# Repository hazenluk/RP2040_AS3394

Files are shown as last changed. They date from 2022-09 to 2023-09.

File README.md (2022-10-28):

# RP2040_AS3394
An AS3394 Voice Card controlled by RP2040.

Schematics and Routing in KiCad. Uses 30Khz PWM with 12-bit duty cycle and 1KHz Low Pass filtering to produce control voltages.

Mainly a way for me to learn and experiment with discrete Sallen-Key and MFB filters. Also a way to avoid out-of-stock DACs during the chip shortage.

Work-In-Progress photo of board:
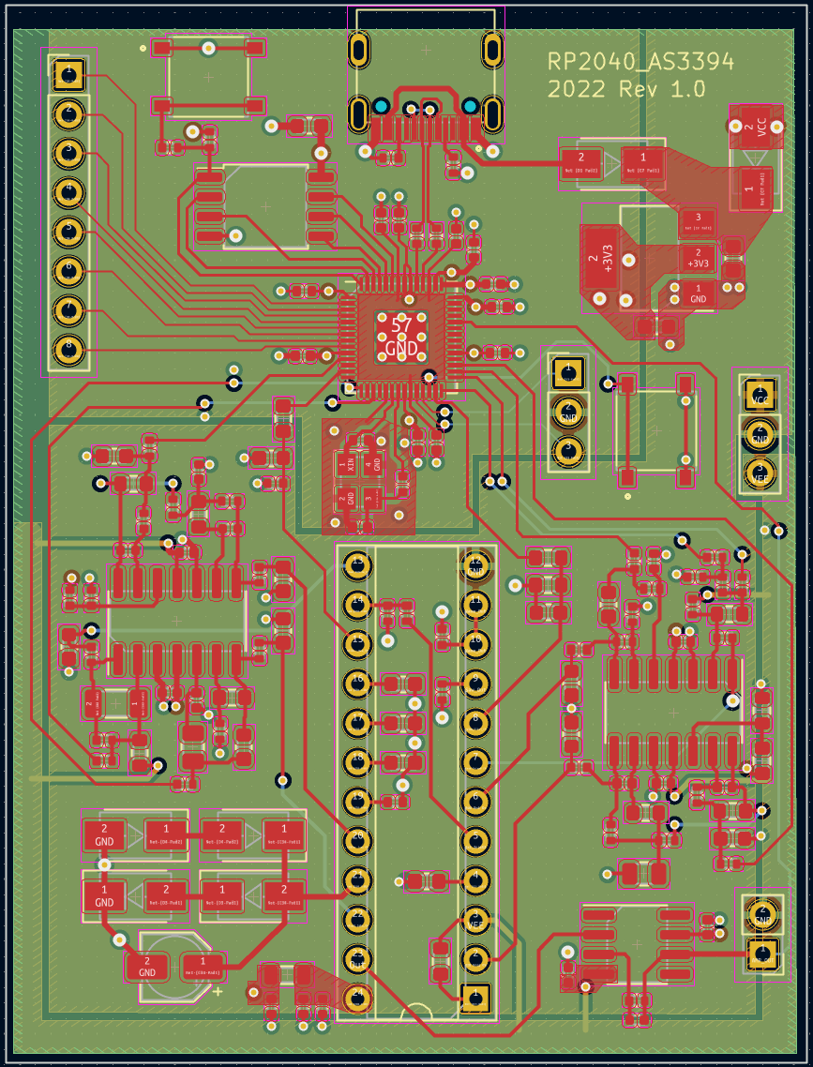
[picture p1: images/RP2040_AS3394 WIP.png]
WIP image of board


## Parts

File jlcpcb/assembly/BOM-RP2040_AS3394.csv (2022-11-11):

Comment | Designator | Footprint | LCSC
120R | FB1 | L_0805_2012Metric | C1015
TL071 | U7 | SOIC-8_3.9x4.9mm_P1.27mm | C107648
1k | R11,R35,R40,R49,R5,R7 | R_0402_1005Metric | C11702
22u | C42 | C_1206_3216Metric | C12891
2k7 | R28,R52 | R_0603_1608Metric | C13167
100n | C16 | C_0603_1608Metric | C14663
NCP1117-3.3_SOT223 | U2 | SOT-223-3_TabPin2 | C146799
10n | C19,C20,C23,C27,C28,C38,C40 | C_0402_1005Metric | C15195
0.1u | C43,C44,C47,C48,C50,C51 | C_0402_1005Metric | C1525
47p | C52 | C_0402_1005Metric | C1567
30p | C14,C15 | C_0402_1005Metric | C1570
1n5 | C17 | C_0603_1608Metric | C1595
15n | C21,C22 | C_0603_1608Metric | C1596
47n | C45,C46 | C_0603_1608Metric | C1622
.047u | C24,C25,C30,C41,C49 | C_0603_1608Metric | C1623
TYPE-C-31-M-12 | J2 | HRO_TYPE-C-31-M-12 | C165948
220n | C39 | C_0402_1005Metric | C16772
16k | R13 | R_0805_2012Metric | C17490
RP2040 | U1 | QFN-56-1EP_7x7mm_P0.4mm_EP3.2x3.2mm | C2040
33n | C18,C32,C33,C35,C37 | C_0603_1608Metric | C21117
D_Schottky | D1,D2 | D_SMA | C22452
3k6 | R45 | R_0603_1608Metric | C22980
4k3 | R50 | R_0603_1608Metric | C23159
560 | R24 | R_0603_1608Metric | C23204
750 | R23 | R_0603_1608Metric | C23241
9k1 | R43 | R_0603_1608Metric | C23260
100 | R30,R48,R57 | R_0402_1005Metric | C25076
120 | R25,R26 | R_0402_1005Metric | C25079
4u7 | C34 | CP_Elec_4x5.4 | C250890
300 | R36 | R_0402_1005Metric | C25102
510 | R14,R22 | R_0402_1005Metric | C25123
10k | R10,R55 | R_0402_1005Metric | C25744
12k | R9 | R_0402_1005Metric | C25752
15k | R12 | R_0402_1005Metric | C25756
18k | R47 | R_0402_1005Metric | C25762
33k | R44 | R_0402_1005Metric | C25779
1k5 | R56 | R_0402_1005Metric | C25867
2k2 | R41 | R_0402_1005Metric | C25879
2k4 | R17,R18 | R_0402_1005Metric | C25882
3k3 | R27,R46 | R_0402_1005Metric | C25890
5.1k | R1,R2,R29 | R_0402_1005Metric | C25905
6k8 | R19,R31,R32,R8 | R_0402_1005Metric | C25917
7.5k | R16 | R_0402_1005Metric | C25918
1k6 | R33 | R_0402_1005Metric | C25931
11k | R21,R34 | R_0603_1608Metric | C25950
100n | C1,C10,C11,C13,C3,C4,C6,C8,C9 | C_0402_1005Metric | C307331
27r4 | R3,R4 | R_0402_1005Metric | C31439
560p | C31 | C_0402_1005Metric | C318606
TS-1187A-B-A-B | S1,S2 | SW_TS-1187A-B-A-B | C318884
68k | R37 | R_0402_1005Metric | C36871
2k | R38,R39,R42 | R_0402_1005Metric | C4109
240k | R15 | R_0603_1608Metric | C4197
3k | R20,R54 | R_0603_1608Metric | C4211
6k2 | R53 | R_0603_1608Metric | C4260
1u | C2,C29,C36,C5 | C_0402_1005Metric | C52923
180n | C26 | C_0805_2012Metric | C67952
LM324 | U4,U6 | SOIC-14_3.9x8.7mm_P1.27mm | C71035
X322512MSB4SI | Y1 | Crystal_SMD_3225-4Pin_3.2x2.5mm | C9002
D_Small | D3,D4,D5,D6 | D_SMA | C95872
10u | C12,C7 | C_0603_1608Metric | C96446
W25Q128JVS | U3 | SOIC-8_5.23x5.23mm_P1.27mm | C97521
DNF | R6 | R_0402_1005Metric
Conn_01x08 | J4 | PinHeader_1x08_P2.54mm_Vertical
AS3394 | U5 | DIP-24_W7.62mm_Socket
Conn_01x03 | J1 | PinHeader_1x03_P2.54mm_Vertical
Conn_01x02 | J3 | PinHeader_1x02_P2.54mm_Vertical
Conn_01x03 | J5 | PinHeader_1x03_P2.54mm_Vertical

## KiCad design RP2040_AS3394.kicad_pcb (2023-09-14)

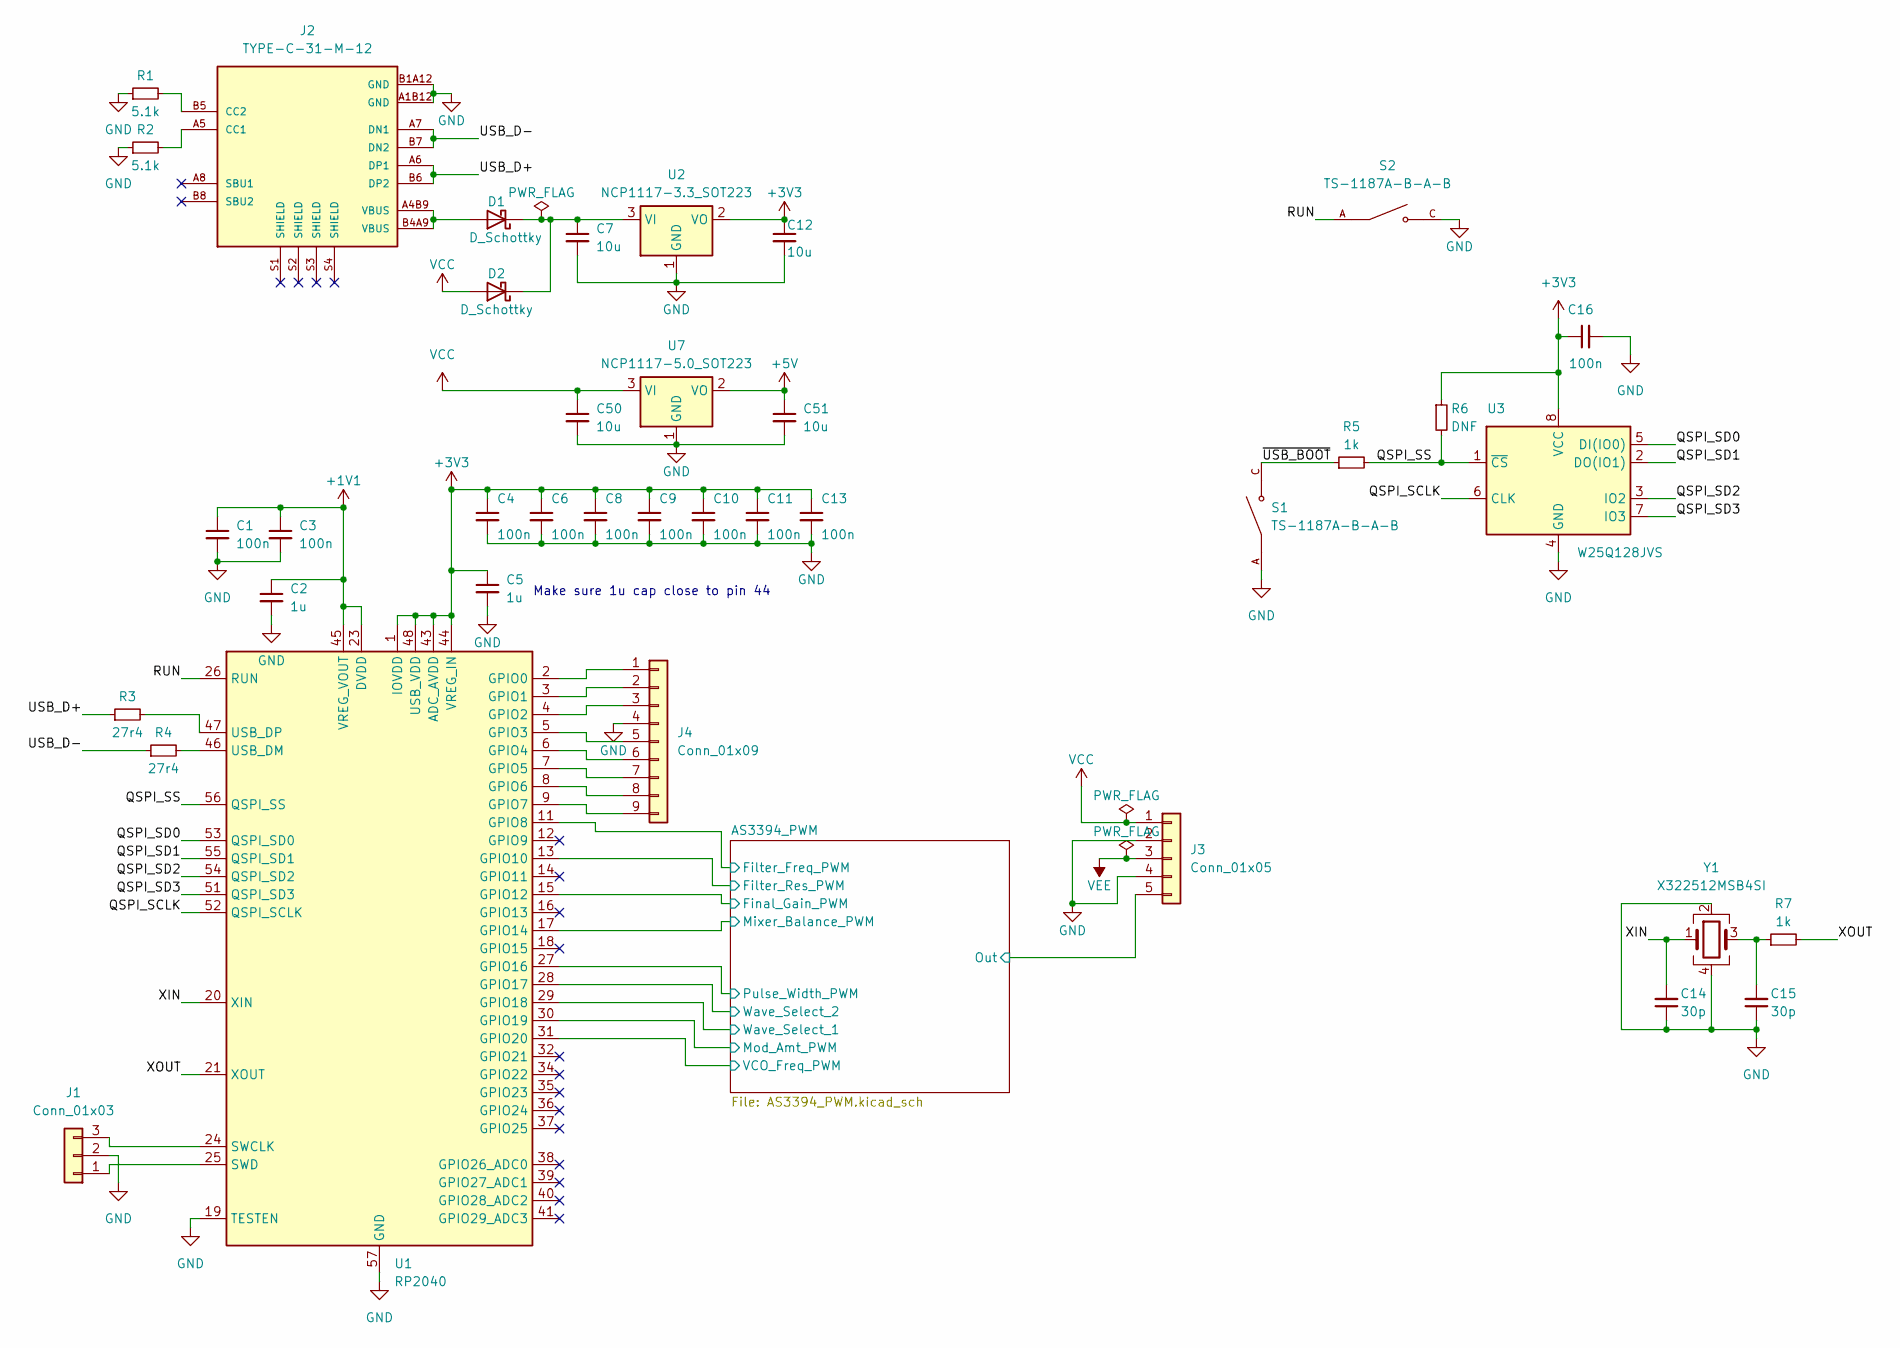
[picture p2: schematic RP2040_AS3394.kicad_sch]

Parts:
C1, C3, C4, C6, C8, C9, C10, C11, C13: 100n; C_0402_1005Metric
C2, C5: 1u; C_0402_1005Metric
C7, C12, C50, C51: 10u; C_0603_1608Metric
C14, C15: 30p; C_0402_1005Metric
C16: 100n; C_0603_1608Metric
D1, D2: D_Schottky; D_SMA
J1: Conn_01x03; PinHeader_1x03_P2.54mm_Vertical
J2: TYPE-C-31-M-12; HRO_TYPE-C-31-M-12; PARTREV A
J3: Conn_01x05; PinHeader_1x05_P2.54mm_Vertical
J4: Conn_01x09; PinHeader_1x09_P2.54mm_Vertical
R1, R2: 5.1k; R_0402_1005Metric
R3, R4: 27r4; R_0402_1005Metric
R5, R7: 1k; R_0402_1005Metric
R6: DNF; R_0402_1005Metric
S1, S2: TS-1187A-B-A-B; SW_TS-1187A-B-A-B; PARTREV A0
U1: RP2040; QFN-56-1EP_7x7mm_P0.4mm_EP3.2x3.2mm
U2: NCP1117-3.3_SOT223; SOT-223-3_TabPin2
U3: W25Q128JVS; SOIC-8_5.23x5.23mm_P1.27mm
U7: NCP1117-5.0_SOT223; SOT-223-3_TabPin2
Y1: X322512MSB4SI; Crystal_SMD_3225-4Pin_3.2x2.5mm

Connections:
+1V1: C1.1, C2.1, C3.1, U1.23 (DVDD), U1.45 (VREG_VOUT), U1.50 (DVDD)
+3V3: C4.1, C5.1, C6.1, C8.1, C9.1, C10.1, C11.1, C12.1, C13.1, C16.1, R6.1, U1.1 (IOVDD), U1.10 (IOVDD), U1.22 (IOVDD), U1.33 (IOVDD), U1.42 (IOVDD), U1.43 (ADC_AVDD), U1.44 (VREG_IN), U1.48 (USB_VDD), U1.49 (IOVDD), U2.2 (VO), U3.8 (VCC)
+5V: C51.1, U7.2 (VO); also elsewhere on the board
/AS3394_PWM/Filter_Freq_PWM: U1.11 (GPIO8); also elsewhere on the board
/AS3394_PWM/Filter_Res_PWM: U1.13 (GPIO10); also elsewhere on the board
/AS3394_PWM/Final_Gain_PWM: U1.15 (GPIO12); also elsewhere on the board
/AS3394_PWM/Mixer_Balance_PWM: U1.17 (GPIO14); also elsewhere on the board
/AS3394_PWM/Mod_Amt_PWM: U1.30 (GPIO19); also elsewhere on the board
/AS3394_PWM/Out: J3.5; also elsewhere on the board
/AS3394_PWM/Pulse_Width_PWM: U1.27 (GPIO16); also elsewhere on the board
/AS3394_PWM/VCO_Freq_PWM: U1.31 (GPIO20); also elsewhere on the board
/AS3394_PWM/Wave_Select_1: U1.29 (GPIO18); also elsewhere on the board
/AS3394_PWM/Wave_Select_2: U1.28 (GPIO17); also elsewhere on the board
/QSPI_SCLK: U1.52 (QSPI_SCLK), U3.6 (CLK)
/QSPI_SD0: U1.53 (QSPI_SD0), U3.5 (DI(IO0))
/QSPI_SD1: U1.55 (QSPI_SD1), U3.2 (DO(IO1))
/QSPI_SD2: U1.54 (QSPI_SD2), U3.3 (IO2)
/QSPI_SD3: U1.51 (QSPI_SD3), U3.7 (IO3)
/QSPI_SS: R5.2, R6.2, U1.56 (QSPI_SS), U3.1 (~CS)
/RUN: S2.A, S2.B, U1.26 (RUN)
/USB_D+: J2.A6 (DP1), J2.B6 (DP2), R3.1
/USB_D-: J2.A7 (DN1), J2.B7 (DN2), R4.1
/XIN: C14.2, U1.20 (XIN), Y1.1
/XOUT: R7.2, U1.21 (XOUT)
/~USB_BOOT: R5.1, S1.C, S1.D
GND: C1.2, C2.2, C3.2, C4.2, C5.2, C6.2, C7.2, C8.2, C9.2, C10.2, C11.2, C12.2, C13.2, C14.1, C15.1, C16.2, C50.2, C51.2, J1.2, J2.A1B12 (GND), J2.B1A12 (GND), J3.2, J3.4, J4.4, R1.1, R2.1, S1.A, S1.B, S2.C, S2.D, U1.19 (TESTEN), U1.57 (GND), U2.1 (GND), U3.4 (GND), U7.1 (GND), Y1.2, Y1.4; also elsewhere on the board
unnamed: C15.2, R7.1, Y1.3
unnamed: D1.2 (A), J2.A4B9 (VBUS), J2.B4A9 (VBUS)
unnamed: C7.1, D1.1 (K), D2.1 (K), U2.3 (VI)
unnamed: J1.1, U1.25 (SWD)
unnamed: J1.3, U1.24 (SWCLK)
unnamed: J2.A5 (CC1), R2.2
unnamed: J2.B5 (CC2), R1.2
unnamed: J4.1, U1.2 (GPIO0)
unnamed: J4.2, U1.3 (GPIO1)
unnamed: J4.3, U1.4 (GPIO2)
unnamed: J4.5, U1.5 (GPIO3)
unnamed: J4.6, U1.6 (GPIO4)
unnamed: J4.7, U1.7 (GPIO5)
unnamed: J4.8, U1.8 (GPIO6)
unnamed: J4.9, U1.9 (GPIO7)
unnamed: R4.2, U1.46 (USB_DM)
unnamed: R3.2, U1.47 (USB_DP)
VCC: C50.1, D2.2 (A), J3.1, U7.3 (VI); also elsewhere on the board
VEE: J3.3; also elsewhere on the board

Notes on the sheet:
Make sure 1u cap close to pin 44

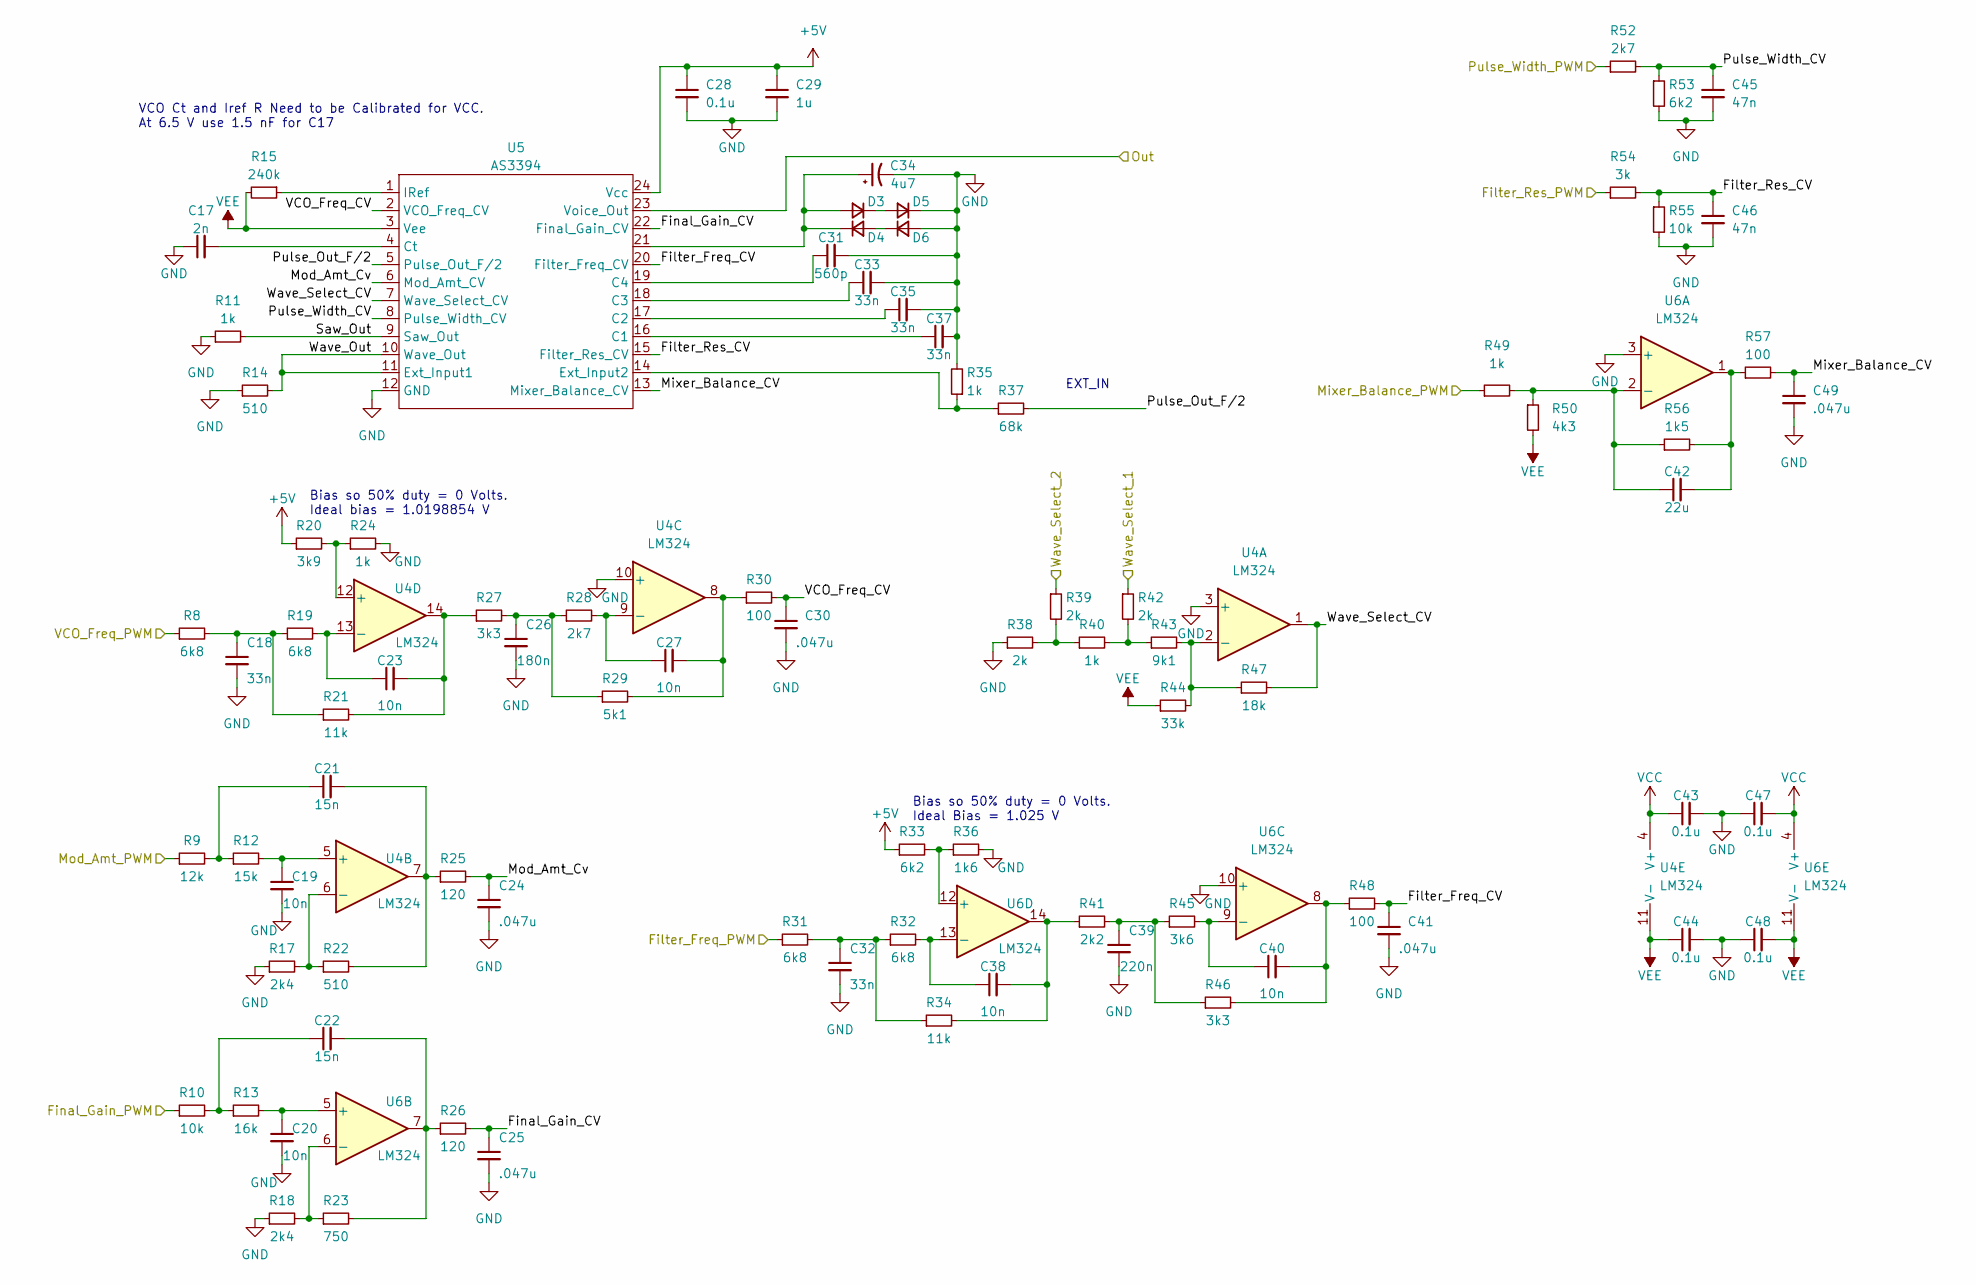
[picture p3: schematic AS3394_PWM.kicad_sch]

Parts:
C17: 2n; C_0603_1608Metric
C18, C32, C33, C35, C37: 33n; C_0603_1608Metric
C19, C20, C23, C27, C38, C40: 10n; C_0402_1005Metric
C21, C22: 15n; C_0603_1608Metric
C24, C25, C30, C41, C49: .047u; C_0603_1608Metric
C26: 180n; C_0805_2012Metric
C28, C43, C44, C47, C48: 0.1u; C_0402_1005Metric
C29: 1u; C_0402_1005Metric
C31: 560p; C_0402_1005Metric
C34: 4u7; CP_Elec_4x5.4
C39: 220n; C_0402_1005Metric
C42: 22u; C_1206_3216Metric
C45, C46: 47n; C_0603_1608Metric
D3, D4, D5, D6: D_Small; D_SOD-123
R8, R19, R31, R32: 6k8; R_0402_1005Metric
R9: 12k; R_0402_1005Metric
R10, R55: 10k; R_0402_1005Metric
R11, R24, R35, R40, R49: 1k; R_0402_1005Metric
R12: 15k; R_0402_1005Metric
R13: 16k; R_0805_2012Metric
R14, R22: 510; R_0402_1005Metric
R15: 240k; R_0603_1608Metric
R17, R18: 2k4; R_0402_1005Metric
R20: 3k9; R_0402_1005Metric
R21, R34: 11k; R_0603_1608Metric
R23: 750; R_0603_1608Metric
R25, R26: 120; R_0402_1005Metric
R27, R46: 3k3; R_0402_1005Metric
R28, R52: 2k7; R_0603_1608Metric
R29: 5k1; R_0402_1005Metric
R30, R48, R57: 100; R_0402_1005Metric
R33, R53: 6k2; R_0603_1608Metric
R36: 1k6; R_0402_1005Metric
R37: 68k; R_0402_1005Metric
R38, R39, R42: 2k; R_0402_1005Metric
R41: 2k2; R_0402_1005Metric
R43: 9k1; R_0603_1608Metric
R44: 33k; R_0402_1005Metric
R45: 3k6; R_0603_1608Metric
R47: 18k; R_0402_1005Metric
R50: 4k3; R_0603_1608Metric
R54: 3k; R_0603_1608Metric
R56: 1k5; R_0402_1005Metric
U4, U6: LM324; SOIC-14_3.9x8.7mm_P1.27mm
U5: AS3394; DIP-24_W7.62mm_Socket

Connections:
+5V: C28.1, C29.1, R20.1, R33.1, U5.24 (Vcc); also elsewhere on the board
/AS3394_PWM/Filter_Freq_CV: C41.1, R48.2, U5.20 (Filter_Freq_CV)
/AS3394_PWM/Filter_Freq_PWM: R31.1; also elsewhere on the board
/AS3394_PWM/Filter_Res_CV: C46.1, R54.2, R55.1, U5.15 (Filter_Res_CV)
/AS3394_PWM/Filter_Res_PWM: R54.1; also elsewhere on the board
/AS3394_PWM/Final_Gain_CV: C25.1, R26.2, U5.22 (Final_Gain_CV)
/AS3394_PWM/Final_Gain_PWM: R10.1; also elsewhere on the board
/AS3394_PWM/Mixer_Balance_CV: C49.1, R57.2, U5.13 (Mixer_Balance_CV)
/AS3394_PWM/Mixer_Balance_PWM: R49.1; also elsewhere on the board
/AS3394_PWM/Mod_Amt_Cv: C24.1, R25.2, U5.6 (Mod_Amt_CV)
/AS3394_PWM/Mod_Amt_PWM: R9.1; also elsewhere on the board
/AS3394_PWM/Out: U5.23 (Voice_Out); also elsewhere on the board
/AS3394_PWM/Pulse_Out_F/2: R37.2, U5.5 (Pulse_Out_F/2)
/AS3394_PWM/Pulse_Width_CV: C45.1, R52.2, R53.1, U5.8 (Pulse_Width_CV)
/AS3394_PWM/Pulse_Width_PWM: R52.1; also elsewhere on the board
/AS3394_PWM/Saw_Out: R11.2, U5.9 (Saw_Out)
/AS3394_PWM/VCO_Freq_CV: C30.1, R30.2, U5.2 (VCO_Freq_CV)
/AS3394_PWM/VCO_Freq_PWM: R8.1; also elsewhere on the board
/AS3394_PWM/Wave_Out: R14.2, U5.10 (Wave_Out), U5.11 (Ext_Input1)
/AS3394_PWM/Wave_Select_1: R42.1; also elsewhere on the board
/AS3394_PWM/Wave_Select_2: R39.1; also elsewhere on the board
/AS3394_PWM/Wave_Select_CV: R47.2, U4.1, U5.7 (Wave_Select_CV)
GND: C17.1, C18.2, C19.2, C20.2, C24.2, C25.2, C26.2, C28.2, C29.2, C30.2, C31.2, C32.2, C33.2, C34.2, C35.2, C37.2, C39.2, C41.2, C43.2, C44.2, C45.2, C46.2, C47.1, C48.1, C49.2, D5.1 (K), D6.2 (A), R11.1, R14.1, R17.1, R18.1, R24.2, R35.2, R36.2, R38.1, R53.2, R55.2, U4.3 (+), U4.10 (+), U5.12 (GND), U6.3 (+), U6.10 (+); also elsewhere on the board
unnamed: C18.1, R8.2, R19.1, R21.1
unnamed: C21.1, R9.2, R12.1
unnamed: C21.2, R22.2, R25.1, U4.7
unnamed: C22.1, R10.2, R13.1
unnamed: C22.2, R23.2, R26.1, U6.7
unnamed: C23.2, R21.2, R27.1, U4.14
unnamed: C26.1, R27.2, R28.1, R29.1
unnamed: C27.2, R29.2, R30.1, U4.8
unnamed: C32.1, R31.2, R32.1, R34.1
unnamed: C38.2, R34.2, R41.1, U6.14
unnamed: C39.1, R41.2, R45.1, R46.1
unnamed: C40.2, R46.2, R48.1, U6.8
unnamed: C42.2, R56.2, R57.1, U6.1
unnamed: C34.1, D3.2 (A), D4.1 (K), U5.21
unnamed: D3.1 (K), D5.2 (A)
unnamed: D4.2 (A), D6.1 (K)
unnamed: R38.2, R39.2, R40.1
unnamed: R40.2, R42.2, R43.1
unnamed: R43.2, R44.2, R47.1, U4.2 (-)
unnamed: C19.1, R12.2, U4.5 (+)
unnamed: R17.2, R22.1, U4.6 (-)
unnamed: C27.1, R28.2, U4.9 (-)
unnamed: R20.2, R24.1, U4.12 (+)
unnamed: C23.1, R19.2, U4.13 (-)
unnamed: C37.1, U5.16 (C1)
unnamed: C35.1, U5.17 (C2)
unnamed: C33.1, U5.18 (C3)
unnamed: C31.1, U5.19 (C4)
unnamed: C17.2, U5.4 (Ct)
unnamed: R35.1, R37.1, U5.14 (Ext_Input2)
unnamed: R15.1, U5.1 (IRef)
unnamed: C42.1, R49.2, R50.1, R56.1, U6.2 (-)
unnamed: C20.1, R13.2, U6.5 (+)
unnamed: R18.2, R23.1, U6.6 (-)
unnamed: C40.1, R45.2, U6.9 (-)
unnamed: R33.2, R36.1, U6.12 (+)
unnamed: C38.1, R32.2, U6.13 (-)
VCC: C43.1, C47.2, U4.4 (V+), U6.4 (V+); also elsewhere on the board
VEE: C44.1, C48.2, R15.2, R44.1, R50.2, U4.11 (V-), U5.3 (Vee), U6.11 (V-); also elsewhere on the board

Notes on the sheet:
Bias so 50% duty = 0 Volts. Ideal Bias = 1.025 V
EXT_IN
Bias so 50% duty = 0 Volts. Ideal bias = 1.0198854 V
VCO Ct and Iref R Need to be Calibrated for VCC. At 6.5 V use 1.5 nF for C17

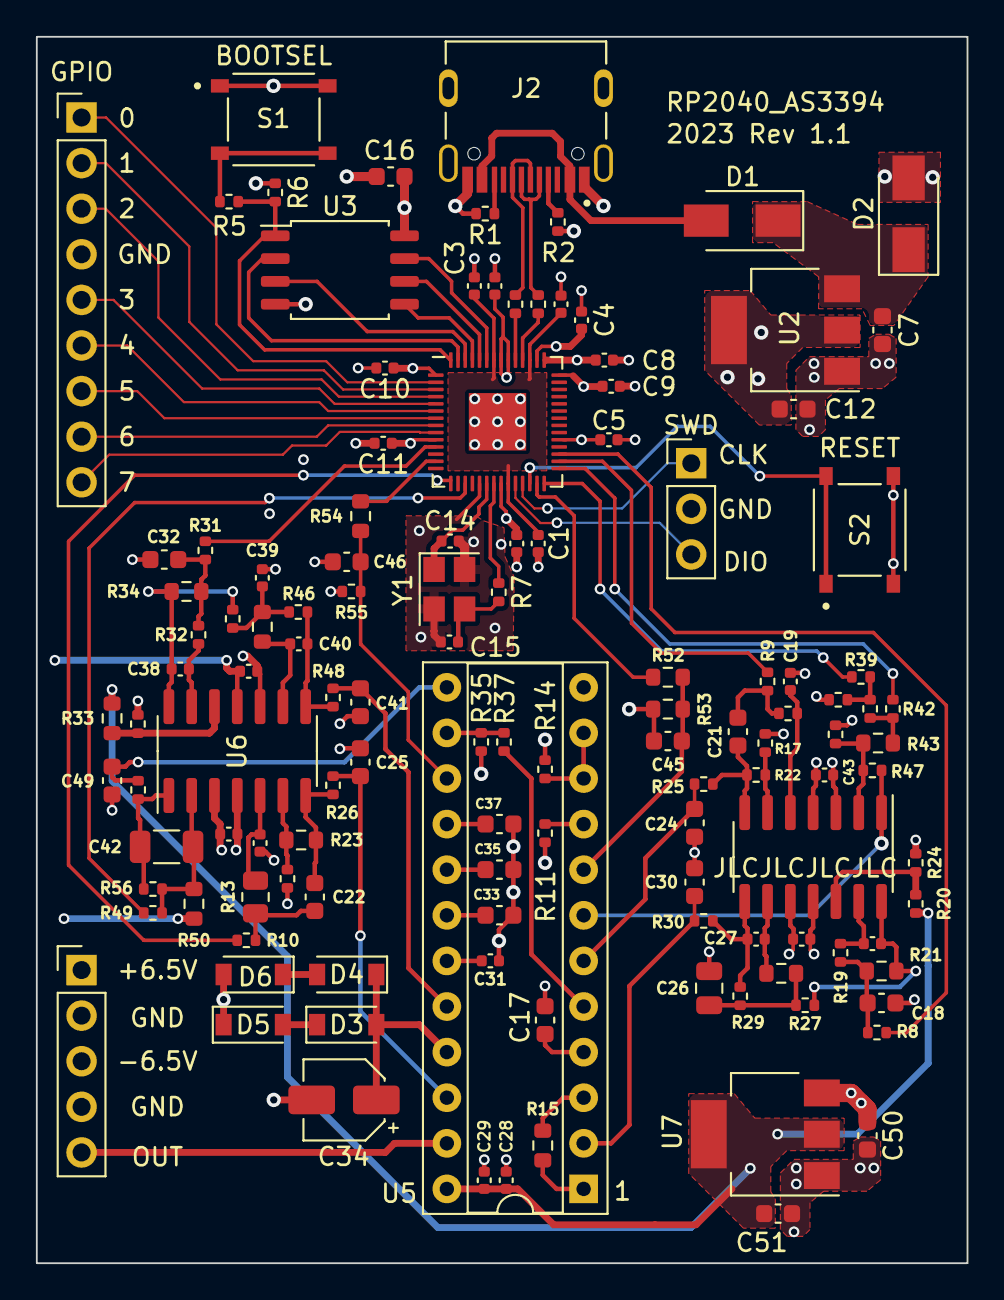
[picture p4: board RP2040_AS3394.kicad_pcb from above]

Board: 4 copper layers, 51.8 x 68.3 mm, 125 parts (0 on the bottom side), 93 nets.

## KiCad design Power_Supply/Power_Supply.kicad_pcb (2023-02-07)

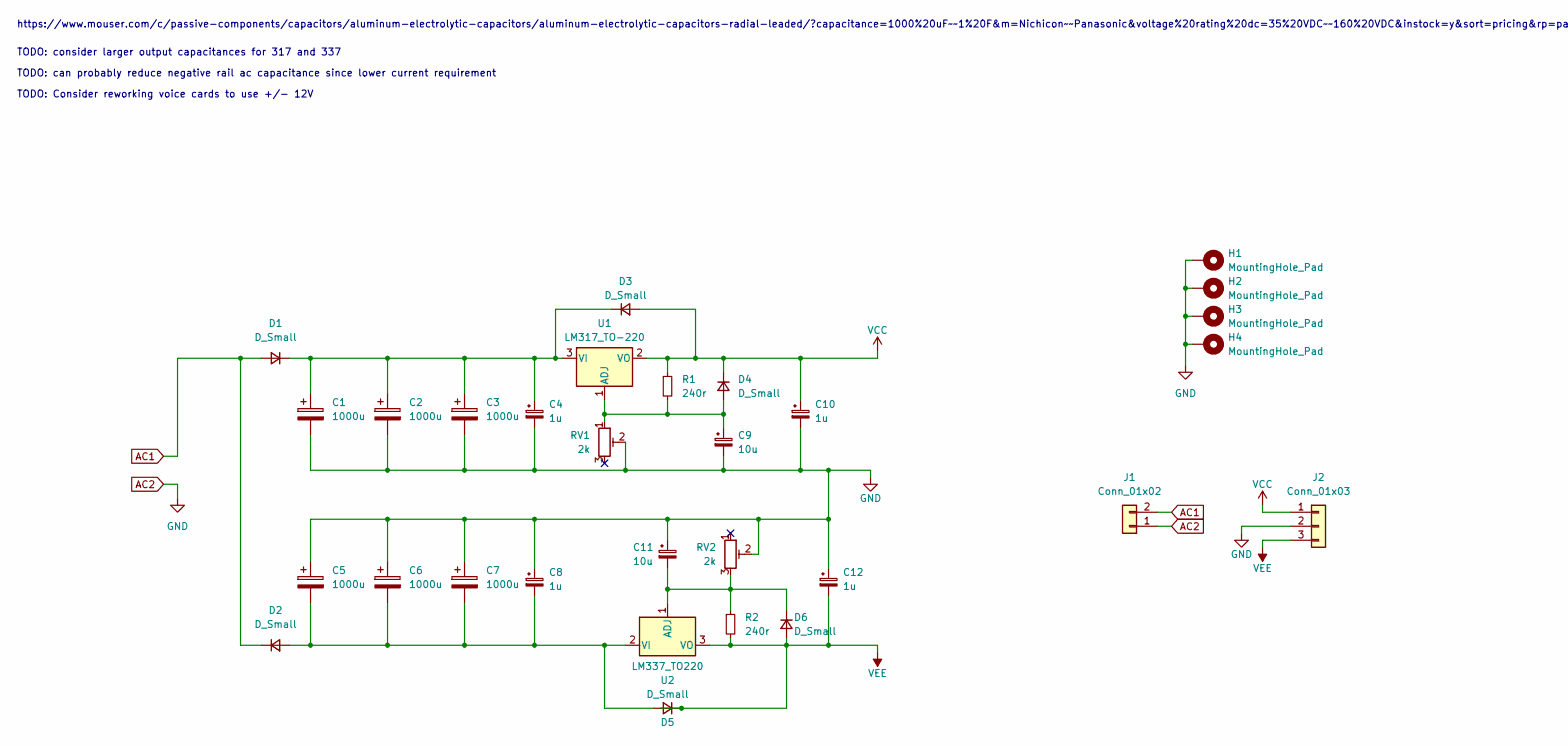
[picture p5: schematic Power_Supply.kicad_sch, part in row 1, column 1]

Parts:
C1, C2, C3, C5, C6, C7: 1000u; CP_Radial_D16.0mm_P7.50mm
C4, C8, C10, C12: 1u; C_Rect_L4.6mm_W2.0mm_P2.50mm_MKS02_FKP02
C9, C11: 10u; CP_Radial_D6.3mm_P2.50mm
D1, D2, D3, D4, D5, D6: D_Small; D_DO-41_SOD81_P7.62mm_Horizontal
H1, H2, H3, H4: MountingHole_Pad; MountingHole_3.2mm_M3_DIN965_Pad
J1: Conn_01x02; PinHeader_1x02_P2.54mm_Vertical
J2: Conn_01x03; PinHeader_1x03_P2.54mm_Vertical
R1, R2: 240r; R_Axial_DIN0204_L3.6mm_D1.6mm_P7.62mm_Horizontal
RV1, RV2: 2k; Potentiometer_Runtron_RM-065_Vertical
U1: LM317_TO-220; TO-220-3_Vertical
U2: LM337_TO220; TO-220-3_Vertical

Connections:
AC1: D1.2 (A), D2.1 (K), J1.2
AC2: C1.2, C2.2, C3.2, C4.2, C5.1, C6.1, C7.1, C8.1, C9.2, C10.2, C11.1, C12.1, H1.1, H2.1, H3.1, H4.1, J1.1, J2.2, RV1.2, RV2.2
unnamed: C1.1, C2.1, C3.1, C4.1, D1.1 (K), D3.1 (K), U1.3 (VI)
unnamed: C5.2, C6.2, C7.2, C8.2, D2.2 (A), D5.2 (A), U2.2 (VI)
unnamed: C9.1, D4.2 (A), R1.2, RV1.1, U1.1 (ADJ)
unnamed: C11.2, D6.1 (K), R2.1, RV2.3, U2.1 (ADJ)
VCC: C10.1, D3.2 (A), D4.1 (K), J2.1, R1.1, U1.2 (VO)
VEE: C12.2, D5.1 (K), D6.2 (A), J2.3, R2.2, U2.3 (VO)

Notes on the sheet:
TODO: consider larger output capacitances for 317 and 337
https://www.mouser.com/c/passive-components/capacitors/aluminum-electrolytic-capacitors/aluminum-electrolytic-capacitors-radial-leaded/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…
TODO: can probably reduce negative rail ac capacitance since lower current requirement
TODO: Consider reworking voice cards to use +/- 12V

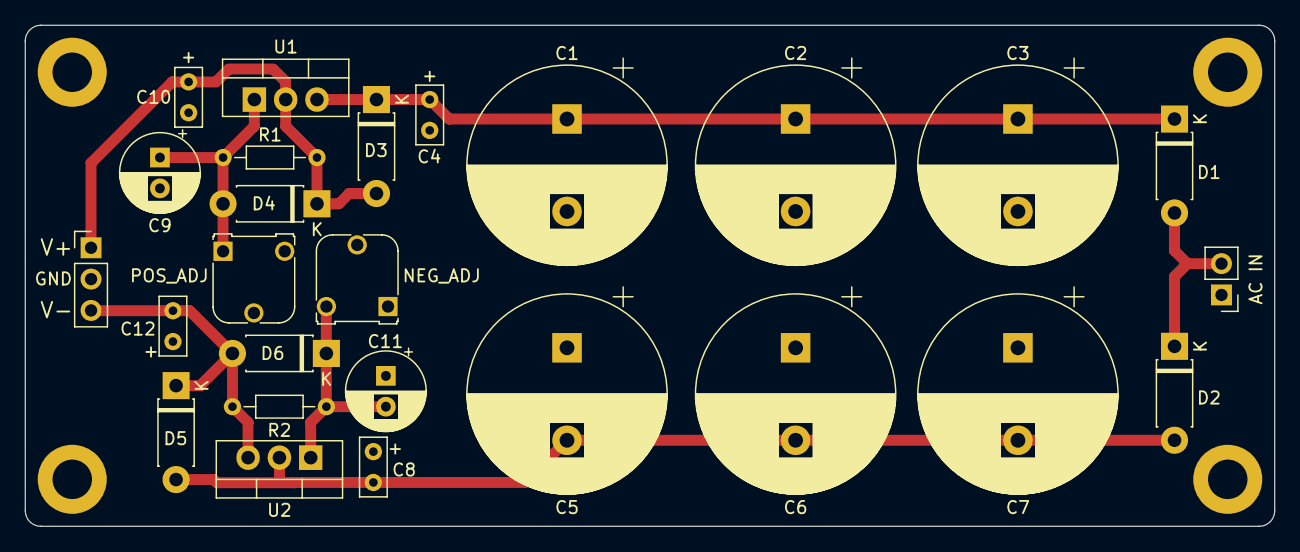
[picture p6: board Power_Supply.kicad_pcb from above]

Board: 2 copper layers, 101.3 x 40.6 mm, 30 parts (0 on the bottom side), 8 nets.

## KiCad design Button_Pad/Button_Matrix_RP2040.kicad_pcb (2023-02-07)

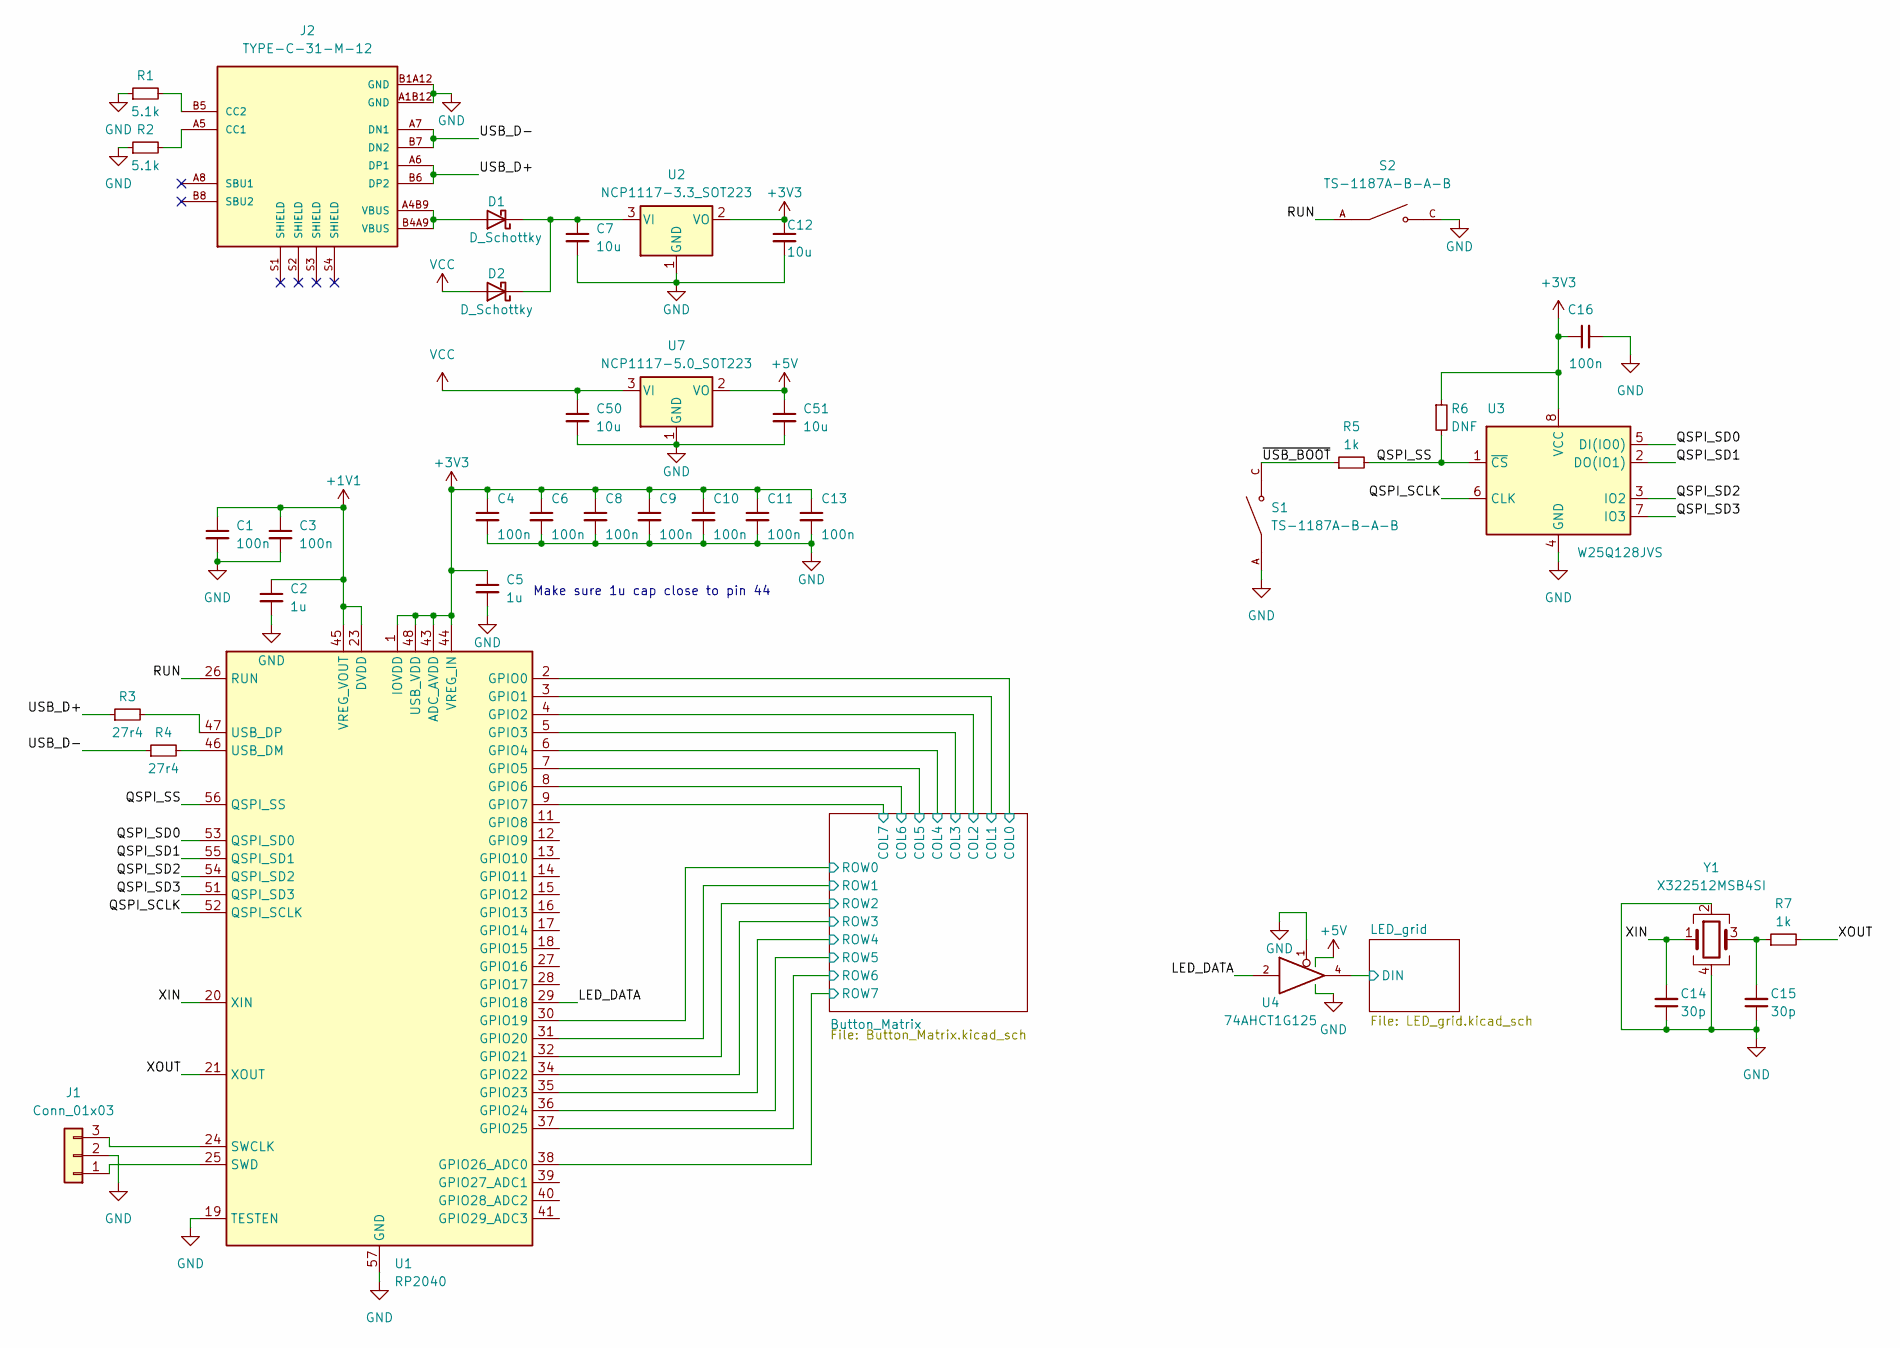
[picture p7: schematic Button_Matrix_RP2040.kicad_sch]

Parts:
C1, C3, C4, C6, C8, C9, C10, C11, C13: 100n; C_0402_1005Metric
C2, C5: 1u; C_0402_1005Metric
C7, C12, C50, C51: 10u; C_0603_1608Metric
C14, C15: 30p; C_0402_1005Metric
C16: 100n; C_0603_1608Metric
D1, D2: D_Schottky; D_SMA
J1: Conn_01x03; PinHeader_1x03_P2.54mm_Vertical
J2: TYPE-C-31-M-12; HRO_TYPE-C-31-M-12; PARTREV A
R1, R2: 5.1k; R_0402_1005Metric
R3, R4: 27r4; R_0402_1005Metric
R5, R7: 1k; R_0402_1005Metric
R6: DNF; R_0402_1005Metric
S1, S2: TS-1187A-B-A-B; SW_TS-1187A-B-A-B; PARTREV A0
U1: RP2040; QFN-56-1EP_7x7mm_P0.4mm_EP3.2x3.2mm
U2: NCP1117-3.3_SOT223; SOT-223-3_TabPin2
U3: W25Q128JVS; SOIC-8_5.23x5.23mm_P1.27mm
U4: 74AHCT1G125; SOT-23-5
U7: NCP1117-5.0_SOT223; SOT-223-3_TabPin2
Y1: X322512MSB4SI; Crystal_SMD_3225-4Pin_3.2x2.5mm

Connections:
+1V1: C1.1, C2.1, C3.1, U1.23 (DVDD), U1.45 (VREG_VOUT), U1.50 (DVDD)
+3V3: C4.1, C5.1, C6.1, C8.1, C9.1, C10.1, C11.1, C12.1, C13.1, C16.1, R6.1, U1.1 (IOVDD), U1.10 (IOVDD), U1.22 (IOVDD), U1.33 (IOVDD), U1.42 (IOVDD), U1.43 (ADC_AVDD), U1.44 (VREG_IN), U1.48 (USB_VDD), U1.49 (IOVDD), U2.2 (VO), U3.8 (VCC)
/Button_Matrix/COL0: U1.2 (GPIO0); also elsewhere on the board
/Button_Matrix/COL1: U1.3 (GPIO1); also elsewhere on the board
/Button_Matrix/COL2: U1.4 (GPIO2); also elsewhere on the board
/Button_Matrix/COL3: U1.5 (GPIO3); also elsewhere on the board
/Button_Matrix/COL4: U1.6 (GPIO4); also elsewhere on the board
/Button_Matrix/COL5: U1.7 (GPIO5); also elsewhere on the board
/Button_Matrix/COL6: U1.8 (GPIO6); also elsewhere on the board
/Button_Matrix/COL7: U1.9 (GPIO7); also elsewhere on the board
/Button_Matrix/ROW0: U1.30 (GPIO19); also elsewhere on the board
/Button_Matrix/ROW1: U1.31 (GPIO20); also elsewhere on the board
/Button_Matrix/ROW2: U1.32 (GPIO21); also elsewhere on the board
/Button_Matrix/ROW3: U1.34 (GPIO22); also elsewhere on the board
/Button_Matrix/ROW4: U1.35 (GPIO23); also elsewhere on the board
/Button_Matrix/ROW5: U1.36 (GPIO24); also elsewhere on the board
/Button_Matrix/ROW6: U1.37 (GPIO25); also elsewhere on the board
/Button_Matrix/ROW7: U1.38 (GPIO26_ADC0); also elsewhere on the board
/LED_DATA: U1.29 (GPIO18), U4.2
/LED_grid/DIN: U4.4; also elsewhere on the board
/QSPI_SCLK: U1.52 (QSPI_SCLK), U3.6 (CLK)
/QSPI_SD0: U1.53 (QSPI_SD0), U3.5 (DI(IO0))
/QSPI_SD1: U1.55 (QSPI_SD1), U3.2 (DO(IO1))
/QSPI_SD2: U1.54 (QSPI_SD2), U3.3 (IO2)
/QSPI_SD3: U1.51 (QSPI_SD3), U3.7 (IO3)
/QSPI_SS: R5.2, R6.2, U1.56 (QSPI_SS), U3.1 (~CS)
/RUN: S2.A, S2.B, U1.26 (RUN)
/USB_D+: J2.A6 (DP1), J2.B6 (DP2), R3.1
/USB_D-: J2.A7 (DN1), J2.B7 (DN2), R4.1
/XIN: C14.2, U1.20 (XIN), Y1.1
/XOUT: R7.2, U1.21 (XOUT)
/~USB_BOOT: R5.1, S1.C, S1.D
GND: C1.2, C2.2, C3.2, C4.2, C5.2, C6.2, C7.2, C8.2, C9.2, C10.2, C11.2, C12.2, C13.2, C14.1, C15.1, C16.2, C50.2, C51.2, J1.2, J2.A1B12 (GND), J2.B1A12 (GND), R1.1, R2.1, S1.A, S1.B, S2.C, S2.D, U1.19 (TESTEN), U1.57 (GND), U2.1 (GND), U3.4 (GND), U4.1, U4.3 (GND), U7.1 (GND), Y1.2, Y1.4; also elsewhere on the board
unnamed: C7.1, D1.1 (K), D2.1 (K), U2.3 (VI)
unnamed: C15.2, R7.1, Y1.3
unnamed: D1.2 (A), J2.A4B9 (VBUS), J2.B4A9 (VBUS)
unnamed: J1.1, U1.25 (SWD)
unnamed: J1.3, U1.24 (SWCLK)
unnamed: J2.A5 (CC1), R2.2
unnamed: J2.B5 (CC2), R1.2
unnamed: R3.2, U1.47 (USB_DP)
unnamed: R4.2, U1.46 (USB_DM)

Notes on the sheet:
Make sure 1u cap close to pin 44

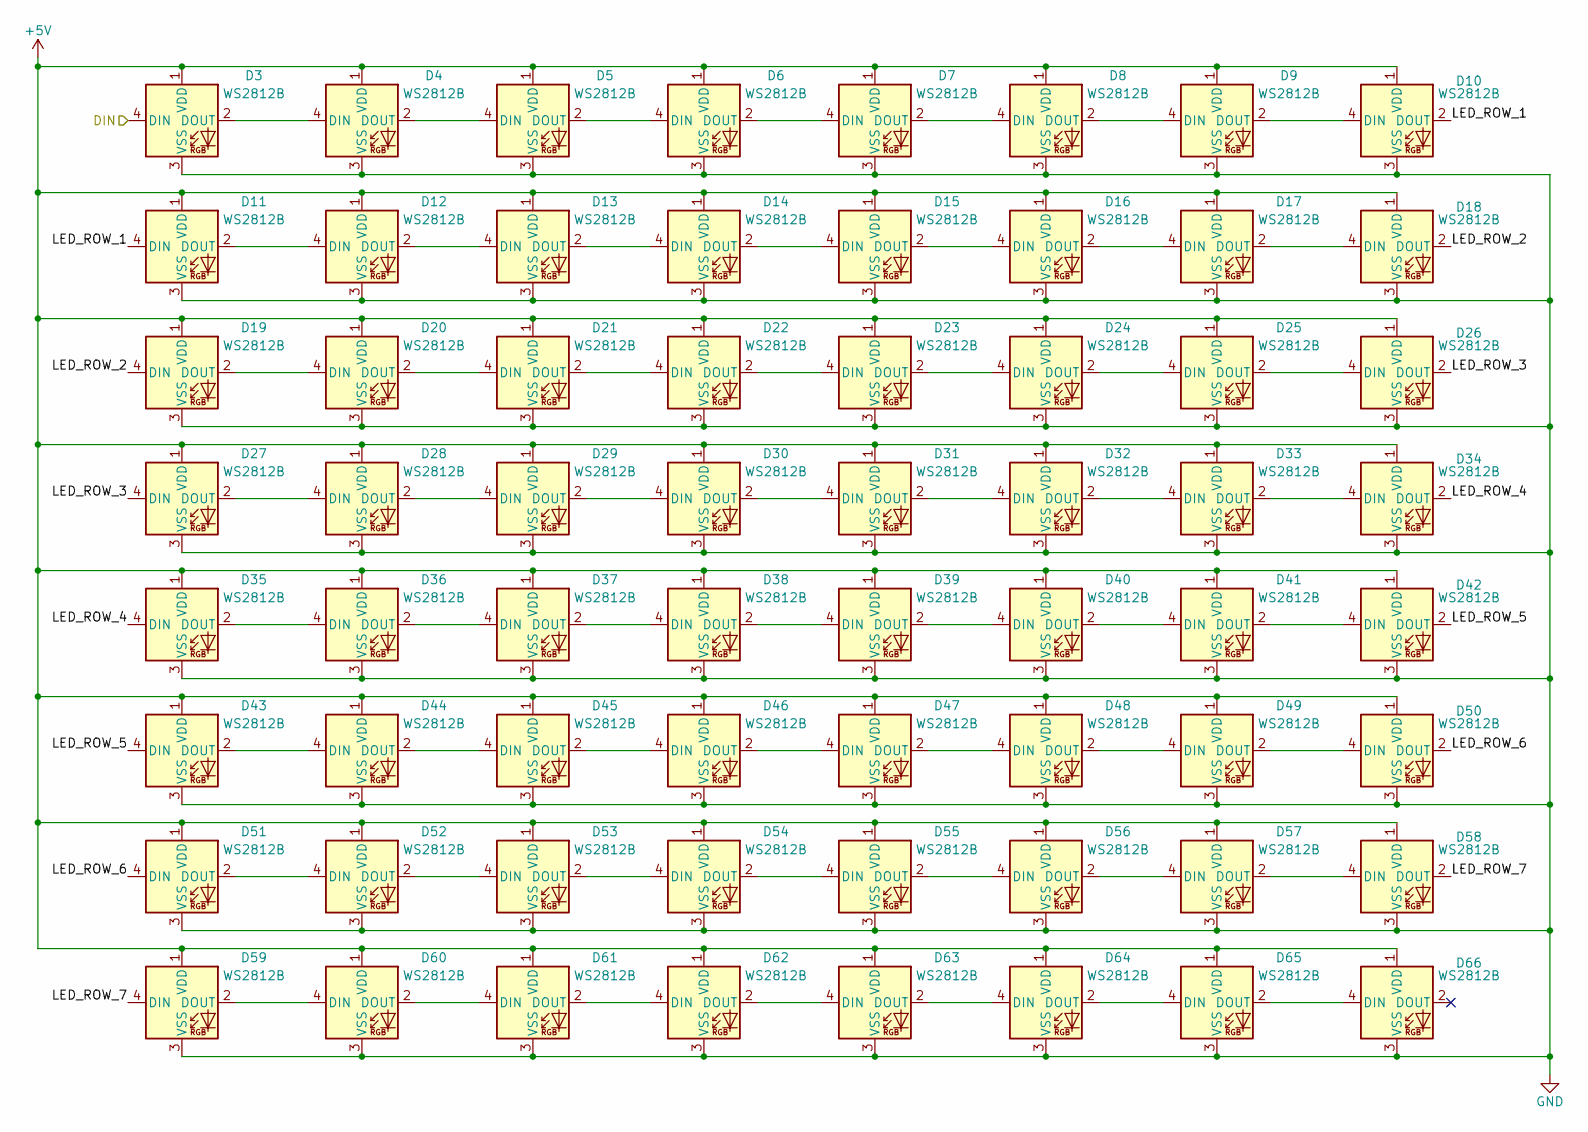
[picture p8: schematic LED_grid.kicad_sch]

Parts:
D3, D4, D5, D6, D7, D8, D9, D10, D11, D12, D13, D14, D15, D16, D17, D18, D19, D20, D21, D22, D23, D24, D25, D26, D27, D28, D29, D30, D31, D32, D33, D34, D35, D36, D37, D38, D39, D40, D41, D42, D43, D44, D45, D46, D47, D48, D49, D50, D51, D52, D53, D54, D55, D56, D57, D58, D59, D60, D61, D62, D63, D64, D65, D66: WS2812B; LED_WS2812B-2020_PLCC4_2.0x2.0mm

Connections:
/LED_grid/DIN: D3.4 (DIN); also elsewhere on the board
/LED_grid/LED_ROW_1: D10.2 (DOUT), D11.4 (DIN)
/LED_grid/LED_ROW_2: D18.2 (DOUT), D19.4 (DIN)
/LED_grid/LED_ROW_3: D26.2 (DOUT), D27.4 (DIN)
/LED_grid/LED_ROW_4: D34.2 (DOUT), D35.4 (DIN)
/LED_grid/LED_ROW_5: D42.2 (DOUT), D43.4 (DIN)
/LED_grid/LED_ROW_6: D50.2 (DOUT), D51.4 (DIN)
/LED_grid/LED_ROW_7: D58.2 (DOUT), D59.4 (DIN)
GND: D3.3 (VSS), D4.3 (VSS), D5.3 (VSS), D6.3 (VSS), D7.3 (VSS), D8.3 (VSS), D9.3 (VSS), D10.3 (VSS), D11.3 (VSS), D12.3 (VSS), D13.3 (VSS), D14.3 (VSS), D15.3 (VSS), D16.3 (VSS), D17.3 (VSS), D18.3 (VSS), D19.3 (VSS), D20.3 (VSS), D21.3 (VSS), D22.3 (VSS), D23.3 (VSS), D24.3 (VSS), D25.3 (VSS), D26.3 (VSS), D27.3 (VSS), D28.3 (VSS), D29.3 (VSS), D30.3 (VSS), D31.3 (VSS), D32.3 (VSS), D33.3 (VSS), D34.3 (VSS), D35.3 (VSS), D36.3 (VSS), D37.3 (VSS), D38.3 (VSS), D39.3 (VSS), D40.3 (VSS), D41.3 (VSS), D42.3 (VSS), D43.3 (VSS), D44.3 (VSS), D45.3 (VSS), D46.3 (VSS), D47.3 (VSS), D48.3 (VSS), D49.3 (VSS), D50.3 (VSS), D51.3 (VSS), D52.3 (VSS), D53.3 (VSS), D54.3 (VSS), D55.3 (VSS), D56.3 (VSS), D57.3 (VSS), D58.3 (VSS), D59.3 (VSS), D60.3 (VSS), D61.3 (VSS), D62.3 (VSS), D63.3 (VSS), D64.3 (VSS), D65.3 (VSS), D66.3 (VSS); also elsewhere on the board
unnamed: D3.2 (DOUT), D4.4 (DIN)
unnamed: D4.2 (DOUT), D5.4 (DIN)
unnamed: D5.2 (DOUT), D6.4 (DIN)
unnamed: D6.2 (DOUT), D7.4 (DIN)
unnamed: D7.2 (DOUT), D8.4 (DIN)
unnamed: D8.2 (DOUT), D9.4 (DIN)
unnamed: D9.2 (DOUT), D10.4 (DIN)
unnamed: D11.2 (DOUT), D12.4 (DIN)
unnamed: D12.2 (DOUT), D13.4 (DIN)
unnamed: D13.2 (DOUT), D14.4 (DIN)
unnamed: D14.2 (DOUT), D15.4 (DIN)
unnamed: D15.2 (DOUT), D16.4 (DIN)
unnamed: D16.2 (DOUT), D17.4 (DIN)
unnamed: D17.2 (DOUT), D18.4 (DIN)
unnamed: D19.2 (DOUT), D20.4 (DIN)
unnamed: D20.2 (DOUT), D21.4 (DIN)
unnamed: D21.2 (DOUT), D22.4 (DIN)
unnamed: D22.2 (DOUT), D23.4 (DIN)
unnamed: D23.2 (DOUT), D24.4 (DIN)
unnamed: D24.2 (DOUT), D25.4 (DIN)
unnamed: D25.2 (DOUT), D26.4 (DIN)
unnamed: D27.2 (DOUT), D28.4 (DIN)
unnamed: D28.2 (DOUT), D29.4 (DIN)
unnamed: D29.2 (DOUT), D30.4 (DIN)
unnamed: D30.2 (DOUT), D31.4 (DIN)
unnamed: D31.2 (DOUT), D32.4 (DIN)
unnamed: D32.2 (DOUT), D33.4 (DIN)
unnamed: D33.2 (DOUT), D34.4 (DIN)
unnamed: D35.2 (DOUT), D36.4 (DIN)
unnamed: D36.2 (DOUT), D37.4 (DIN)
unnamed: D37.2 (DOUT), D38.4 (DIN)
unnamed: D38.2 (DOUT), D39.4 (DIN)
unnamed: D39.2 (DOUT), D40.4 (DIN)
unnamed: D40.2 (DOUT), D41.4 (DIN)
unnamed: D41.2 (DOUT), D42.4 (DIN)
unnamed: D43.2 (DOUT), D44.4 (DIN)
unnamed: D44.2 (DOUT), D45.4 (DIN)
unnamed: D45.2 (DOUT), D46.4 (DIN)
unnamed: D46.2 (DOUT), D47.4 (DIN)
unnamed: D47.2 (DOUT), D48.4 (DIN)
unnamed: D48.2 (DOUT), D49.4 (DIN)
unnamed: D49.2 (DOUT), D50.4 (DIN)
unnamed: D51.2 (DOUT), D52.4 (DIN)
unnamed: D52.2 (DOUT), D53.4 (DIN)
unnamed: D53.2 (DOUT), D54.4 (DIN)
unnamed: D54.2 (DOUT), D55.4 (DIN)
unnamed: D55.2 (DOUT), D56.4 (DIN)
unnamed: D56.2 (DOUT), D57.4 (DIN)
unnamed: D57.2 (DOUT), D58.4 (DIN)
unnamed: D59.2 (DOUT), D60.4 (DIN)
unnamed: D60.2 (DOUT), D61.4 (DIN)
unnamed: D61.2 (DOUT), D62.4 (DIN)
unnamed: D62.2 (DOUT), D63.4 (DIN)
unnamed: D63.2 (DOUT), D64.4 (DIN)
unnamed: D64.2 (DOUT), D65.4 (DIN)
unnamed: D65.2 (DOUT), D66.4 (DIN)

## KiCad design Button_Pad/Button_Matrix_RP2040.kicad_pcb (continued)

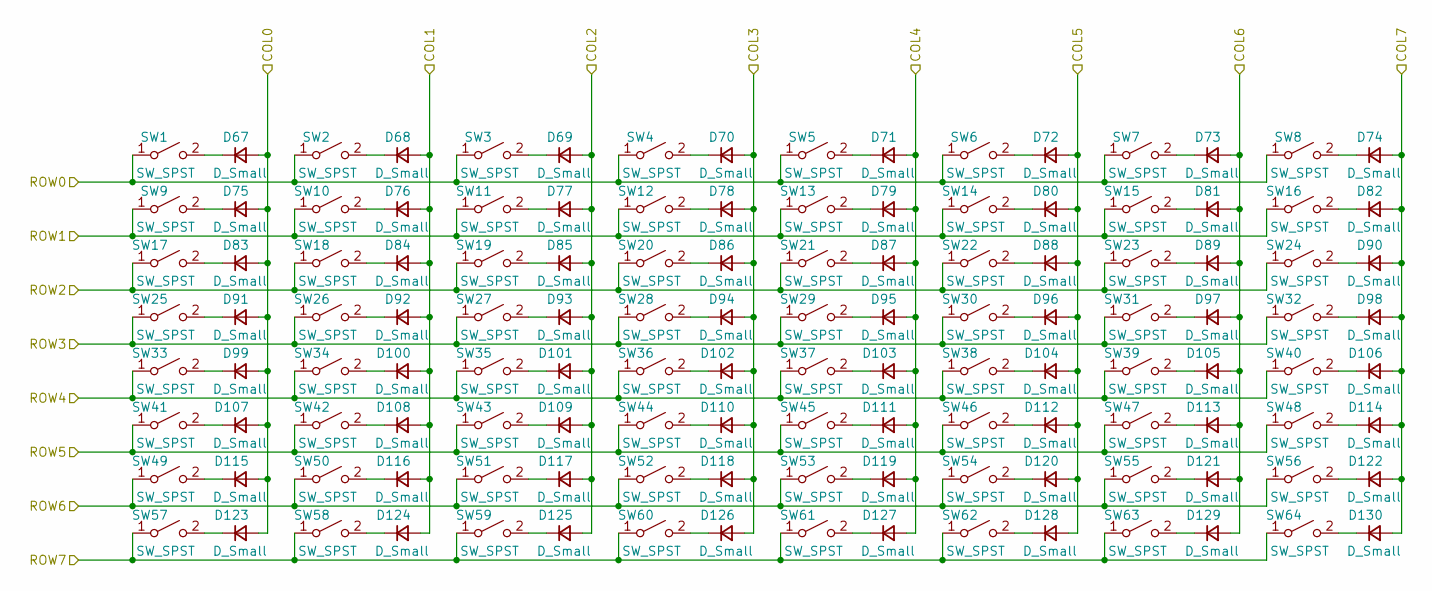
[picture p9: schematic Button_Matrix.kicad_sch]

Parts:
D67, D68, D69, D70, D71, D72, D73, D74, D75, D76, D77, D78, D79, D80, D81, D82, D83, D84, D85, D86, D87, D88, D89, D90, D91, D92, D93, D94, D95, D96, D97, D98, D99, D100, D101, D102, D103, D104, D105, D106, D107, D108, D109, D110, D111, D112, D113, D114, D115, D116, D117, D118, D119, D120, D121, D122, D123, D124, D125, D126, D127, D128, D129, D130: D_Small; D_SOD-323
SW1, SW2, SW3, SW4, SW5, SW6, SW7, SW8, SW9, SW10, SW11, SW12, SW13, SW14, SW15, SW16, SW17, SW18, SW19, SW20, SW21, SW22, SW23, SW24, SW25, SW26, SW27, SW28, SW29, SW30, SW31, SW32, SW33, SW34, SW35, SW36, SW37, SW38, SW39, SW40, SW41, SW42, SW43, SW44, SW45, SW46, SW47, SW48, SW49, SW50, SW51, SW52, SW53, SW54, SW55, SW56, SW57, SW58, SW59, SW60, SW61, SW62, SW63, SW64: SW_SPST; MICROBUILDER_ELAST_PAD_SQUARE_10MM_4X4WIDE

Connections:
/Button_Matrix/COL0: D67.2 (A), D75.2 (A), D83.2 (A), D91.2 (A), D99.2 (A), D107.2 (A), D115.2 (A), D123.2 (A); also elsewhere on the board
/Button_Matrix/COL1: D68.2 (A), D76.2 (A), D84.2 (A), D92.2 (A), D100.2 (A), D108.2 (A), D116.2 (A), D124.2 (A); also elsewhere on the board
/Button_Matrix/COL2: D69.2 (A), D77.2 (A), D85.2 (A), D93.2 (A), D101.2 (A), D109.2 (A), D117.2 (A), D125.2 (A); also elsewhere on the board
/Button_Matrix/COL3: D70.2 (A), D78.2 (A), D86.2 (A), D94.2 (A), D102.2 (A), D110.2 (A), D118.2 (A), D126.2 (A); also elsewhere on the board
/Button_Matrix/COL4: D71.2 (A), D79.2 (A), D87.2 (A), D95.2 (A), D103.2 (A), D111.2 (A), D119.2 (A), D127.2 (A); also elsewhere on the board
/Button_Matrix/COL5: D72.2 (A), D80.2 (A), D88.2 (A), D96.2 (A), D104.2 (A), D112.2 (A), D120.2 (A), D128.2 (A); also elsewhere on the board
/Button_Matrix/COL6: D73.2 (A), D81.2 (A), D89.2 (A), D97.2 (A), D105.2 (A), D113.2 (A), D121.2 (A), D129.2 (A); also elsewhere on the board
/Button_Matrix/COL7: D74.2 (A), D82.2 (A), D90.2 (A), D98.2 (A), D106.2 (A), D114.2 (A), D122.2 (A), D130.2 (A); also elsewhere on the board
/Button_Matrix/ROW0: SW1.1 (A), SW2.1 (A), SW3.1 (A), SW4.1 (A), SW5.1 (A), SW6.1 (A), SW7.1 (A), SW8.1 (A); also elsewhere on the board
/Button_Matrix/ROW1: SW9.1 (A), SW10.1 (A), SW11.1 (A), SW12.1 (A), SW13.1 (A), SW14.1 (A), SW15.1 (A), SW16.1 (A); also elsewhere on the board
/Button_Matrix/ROW2: SW17.1 (A), SW18.1 (A), SW19.1 (A), SW20.1 (A), SW21.1 (A), SW22.1 (A), SW23.1 (A), SW24.1 (A); also elsewhere on the board
/Button_Matrix/ROW3: SW25.1 (A), SW26.1 (A), SW27.1 (A), SW28.1 (A), SW29.1 (A), SW30.1 (A), SW31.1 (A), SW32.1 (A); also elsewhere on the board
/Button_Matrix/ROW4: SW33.1 (A), SW34.1 (A), SW35.1 (A), SW36.1 (A), SW37.1 (A), SW38.1 (A), SW39.1 (A), SW40.1 (A); also elsewhere on the board
/Button_Matrix/ROW5: SW41.1 (A), SW42.1 (A), SW43.1 (A), SW44.1 (A), SW45.1 (A), SW46.1 (A), SW47.1 (A), SW48.1 (A); also elsewhere on the board
/Button_Matrix/ROW6: SW49.1 (A), SW50.1 (A), SW51.1 (A), SW52.1 (A), SW53.1 (A), SW54.1 (A), SW55.1 (A), SW56.1 (A); also elsewhere on the board
/Button_Matrix/ROW7: SW57.1 (A), SW58.1 (A), SW59.1 (A), SW60.1 (A), SW61.1 (A), SW62.1 (A), SW63.1 (A), SW64.1 (A); also elsewhere on the board
unnamed: D67.1 (K), SW1.2 (B)
unnamed: D68.1 (K), SW2.2 (B)
unnamed: D69.1 (K), SW3.2 (B)
unnamed: D70.1 (K), SW4.2 (B)
unnamed: D71.1 (K), SW5.2 (B)
unnamed: D72.1 (K), SW6.2 (B)
unnamed: D73.1 (K), SW7.2 (B)
unnamed: D74.1 (K), SW8.2 (B)
unnamed: D75.1 (K), SW9.2 (B)
unnamed: D76.1 (K), SW10.2 (B)
unnamed: D77.1 (K), SW11.2 (B)
unnamed: D78.1 (K), SW12.2 (B)
unnamed: D79.1 (K), SW13.2 (B)
unnamed: D80.1 (K), SW14.2 (B)
unnamed: D81.1 (K), SW15.2 (B)
unnamed: D82.1 (K), SW16.2 (B)
unnamed: D83.1 (K), SW17.2 (B)
unnamed: D84.1 (K), SW18.2 (B)
unnamed: D85.1 (K), SW19.2 (B)
unnamed: D86.1 (K), SW20.2 (B)
unnamed: D87.1 (K), SW21.2 (B)
unnamed: D88.1 (K), SW22.2 (B)
unnamed: D89.1 (K), SW23.2 (B)
unnamed: D90.1 (K), SW24.2 (B)
unnamed: D91.1 (K), SW25.2 (B)
unnamed: D92.1 (K), SW26.2 (B)
unnamed: D93.1 (K), SW27.2 (B)
unnamed: D94.1 (K), SW28.2 (B)
unnamed: D95.1 (K), SW29.2 (B)
unnamed: D96.1 (K), SW30.2 (B)
unnamed: D97.1 (K), SW31.2 (B)
unnamed: D98.1 (K), SW32.2 (B)
unnamed: D99.1 (K), SW33.2 (B)
unnamed: D100.1 (K), SW34.2 (B)
unnamed: D101.1 (K), SW35.2 (B)
unnamed: D102.1 (K), SW36.2 (B)
unnamed: D103.1 (K), SW37.2 (B)
unnamed: D104.1 (K), SW38.2 (B)
unnamed: D105.1 (K), SW39.2 (B)
unnamed: D106.1 (K), SW40.2 (B)
unnamed: D107.1 (K), SW41.2 (B)
unnamed: D108.1 (K), SW42.2 (B)
unnamed: D109.1 (K), SW43.2 (B)
unnamed: D110.1 (K), SW44.2 (B)
unnamed: D111.1 (K), SW45.2 (B)
unnamed: D112.1 (K), SW46.2 (B)
unnamed: D113.1 (K), SW47.2 (B)
unnamed: D114.1 (K), SW48.2 (B)
unnamed: D115.1 (K), SW49.2 (B)
unnamed: D116.1 (K), SW50.2 (B)
unnamed: D117.1 (K), SW51.2 (B)
unnamed: D118.1 (K), SW52.2 (B)
unnamed: D119.1 (K), SW53.2 (B)
unnamed: D120.1 (K), SW54.2 (B)
unnamed: D121.1 (K), SW55.2 (B)
unnamed: D122.1 (K), SW56.2 (B)
unnamed: D123.1 (K), SW57.2 (B)
unnamed: D124.1 (K), SW58.2 (B)
unnamed: D125.1 (K), SW59.2 (B)
unnamed: D126.1 (K), SW60.2 (B)
unnamed: D127.1 (K), SW61.2 (B)
unnamed: D128.1 (K), SW62.2 (B)
unnamed: D129.1 (K), SW63.2 (B)
unnamed: D130.1 (K), SW64.2 (B)

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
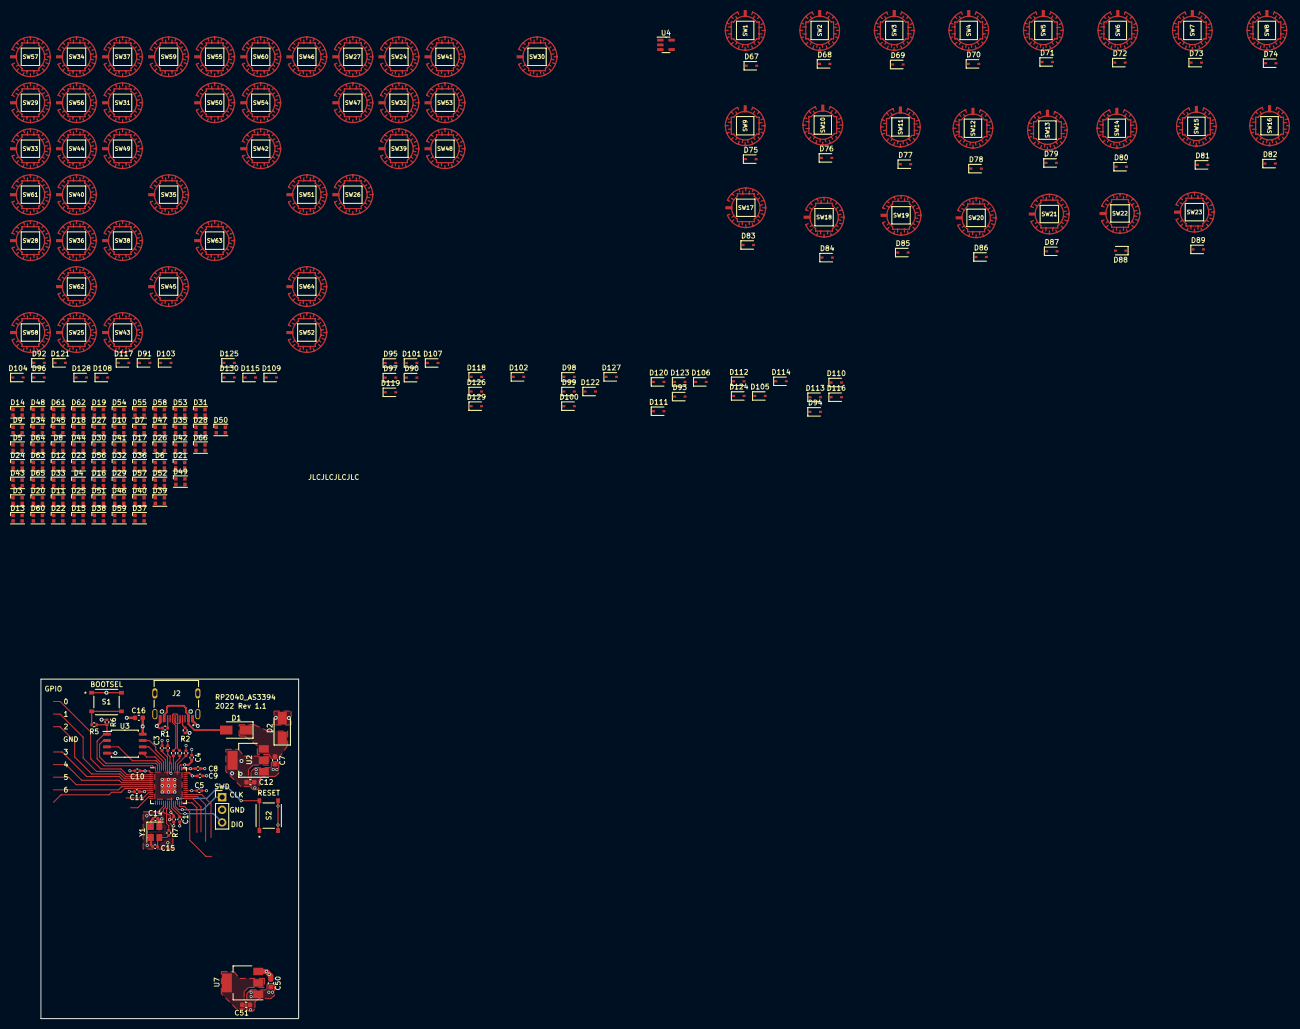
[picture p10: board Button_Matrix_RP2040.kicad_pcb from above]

Board: 4 copper layers, 51.8 x 68.3 mm, 229 parts (0 on the bottom side), 170 nets.

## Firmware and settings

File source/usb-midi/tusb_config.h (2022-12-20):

/*
 * The MIT License (MIT)
 *
 * Copyright (c) 2019 Ha Thach (tinyusb.org)
 *
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
 */

#ifndef _TUSB_CONFIG_H_
#define _TUSB_CONFIG_H_

#ifdef __cplusplus
extern "C" {
#endif

//--------------------------------------------------------------------
// COMMON CONFIGURATION
//--------------------------------------------------------------------

// defined by compiler flags for flexibility
#ifndef CFG_TUSB_MCU
#error CFG_TUSB_MCU must be defined
#endif

#if CFG_TUSB_MCU == OPT_MCU_LPC18XX || CFG_TUSB_MCU == OPT_MCU_LPC43XX || CFG_TUSB_MCU == OPT_MCU_MIMXRT10XX || \
    CFG_TUSB_MCU == OPT_MCU_NUC505 || CFG_TUSB_MCU == OPT_MCU_CXD56
#define CFG_TUSB_RHPORT0_MODE     (OPT_MODE_DEVICE | OPT_MODE_HIGH_SPEED)
#else
#define CFG_TUSB_RHPORT0_MODE     OPT_MODE_DEVICE
#endif

#ifndef CFG_TUSB_OS
#define CFG_TUSB_OS                 OPT_OS_PICO
#endif

// CFG_TUSB_DEBUG is defined by compiler in DEBUG build
// #define CFG_TUSB_DEBUG           0

/* USB DMA on some MCUs can only access a specific SRAM region with restriction on alignment.
 * Tinyusb use follows macros to declare transferring memory so that they can be put
 * into those specific section.
 * e.g
 * - CFG_TUSB_MEM SECTION : __attribute__ (( section(".usb_ram") ))
 * - CFG_TUSB_MEM_ALIGN   : __attribute__ ((aligned(4)))
 */
#ifndef CFG_TUSB_MEM_SECTION
#define CFG_TUSB_MEM_SECTION
#endif

#ifndef CFG_TUSB_MEM_ALIGN
#define CFG_TUSB_MEM_ALIGN          __attribute__ ((aligned(4)))
#endif

//--------------------------------------------------------------------
// DEVICE CONFIGURATION
//--------------------------------------------------------------------

#ifndef CFG_TUD_ENDPOINT0_SIZE
#define CFG_TUD_ENDPOINT0_SIZE    64
#endif

//------------- CLASS -------------//
#define CFG_TUD_CDC             0
#define CFG_TUD_MSC             0
#define CFG_TUD_HID             0
#define CFG_TUD_MIDI            1
#define CFG_TUD_VENDOR          0

// MIDI FIFO size of TX and RX
#define CFG_TUD_MIDI_RX_BUFSIZE   (TUD_OPT_HIGH_SPEED ? 512 : 64)
#define CFG_TUD_MIDI_TX_BUFSIZE   (TUD_OPT_HIGH_SPEED ? 512 : 64)

#ifdef __cplusplus
}
#endif

#endif /* _TUSB_CONFIG_H_ */

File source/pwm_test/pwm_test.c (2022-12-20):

#include "pico/stdlib.h"
#include "hardware/pwm.h"
#include "hardware/adc.h"

#define PWM_PERIOD 4096

#define FILTER_PIN 8
#define RES_PIN 10
#define GAIN_PIN 12
#define MIXER_PIN 14
#define PWM_PIN 16
#define WAVE_SEL_MSB 18
#define WAVE_SEL_LSB 17
#define MOD_PIN 19
#define VCO_PIN 20

// TODO: Consider making an enum type for pwm pins and then making an array so it can be iterated over?

int main() {
    // Init GPIOs allocated to pwm
    gpio_set_function(FILTER_PIN, GPIO_FUNC_PWM);
    gpio_set_function(RES_PIN, GPIO_FUNC_PWM);
    gpio_set_function(GAIN_PIN, GPIO_FUNC_PWM);
    gpio_set_function(MIXER_PIN, GPIO_FUNC_PWM);
    gpio_set_function(PWM_PIN, GPIO_FUNC_PWM);
    gpio_set_function(MOD_PIN, GPIO_FUNC_PWM);
    gpio_set_function(VCO_PIN, GPIO_FUNC_PWM);

    // Init wave select GPIOS
    gpio_init(WAVE_SEL_MSB);
    gpio_init(WAVE_SEL_LSB);
    gpio_set_dir(WAVE_SEL_MSB, GPIO_OUT);
    gpio_set_dir(WAVE_SEL_LSB, GPIO_OUT);

    // Init ADC GPIO
    adc_init();
    adc_gpio_init(26);
    adc_select_input(0);

    // Find out which PWM slice is connected to which GPIO
    uint filter_slice = pwm_gpio_to_slice_num(FILTER_PIN);
    uint res_slice = pwm_gpio_to_slice_num(RES_PIN);
    uint gain_slice = pwm_gpio_to_slice_num(GAIN_PIN);
    uint mixer_slice = pwm_gpio_to_slice_num(MIXER_PIN);
    uint pwm_slice = pwm_gpio_to_slice_num(PWM_PIN);
    uint mod_slice = pwm_gpio_to_slice_num(MOD_PIN);
    uint vco_slice = pwm_gpio_to_slice_num(VCO_PIN);

    // Set PWM periods
    pwm_set_wrap(filter_slice, 4096);
    pwm_set_wrap(res_slice, 4096);
    pwm_set_wrap(gain_slice, 4096);
    pwm_set_wrap(mixer_slice, 4096);
    pwm_set_wrap(pwm_slice, 4096);
    pwm_set_wrap(mod_slice, 4096);
    pwm_set_wrap(vco_slice, 4096);

    // Set pwm channels high for N cycles
    pwm_set_gpio_level(FILTER_PIN, 100);
    pwm_set_gpio_level(RES_PIN, 0);
    pwm_set_gpio_level(GAIN_PIN, 2000); // 3000
    pwm_set_gpio_level(MIXER_PIN, 400); // Main out
    //pwm_set_gpio_level(MIXER_PIN, 3700); // Sub out
    pwm_set_gpio_level(PWM_PIN, 0);
    pwm_set_gpio_level(MOD_PIN, 0);
    pwm_set_gpio_level(VCO_PIN, 2292); //2292 = A440 with 5V reg instead of 6.5

    // Set the PWM running
    pwm_set_enabled(filter_slice, true);
    pwm_set_enabled(res_slice, true);
    pwm_set_enabled(gain_slice, true);
    pwm_set_enabled(mixer_slice, true);
    pwm_set_enabled(pwm_slice, true);
    pwm_set_enabled(mod_slice, true);
    pwm_set_enabled(vco_slice, true);

    // Wave_Sel = 00 = sawtooth
    gpio_put(WAVE_SEL_MSB, 0);
    gpio_put(WAVE_SEL_LSB, 0);
}

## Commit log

2022-09-13 Upload to GitHub. Schematic nearly complete; need to add stereo VCA.
    [AS3394_PWM.kicad_sch, RP2040_AS3394.kicad_pcb, RP2040_AS3394.kicad_sch]
2022-09-14 Finished schema; decided to make voice cards mono and leave stereo mixing to mainboards instead
    [AS3394_PWM.kicad_sch, RP2040_AS3394.kicad_sch]
2022-09-14 Last commit was a lie. Added bypass caps and power conns to LM324s.
    [AS3394_PWM.kicad_sch, RP2040_AS3394.kicad_sch]
2022-10-10 Added PWM connections from RP2040 to subsheet containing AS3394; finished assinging components for JLC assembly
    [AS3394_PWM.kicad_sch, RP2040_AS3394.kicad_pcb, RP2040_AS3394.kicad_sch]
2022-10-15 Started placement
    [AS3394_PWM.kicad_sch, RP2040_AS3394.kicad_pcb, RP2040_AS3394.kicad_sch]
2022-10-25 Finished most of routing; added TL071 for headphone out; working on adding I/O
    [AS3394_PWM.kicad_sch, RP2040_AS3394.kicad_pcb, RP2040_AS3394.kicad_sch]
2022-10-25 Mostly finished, just need to review and add final touches
    [RP2040_AS3394.kicad_pcb, RP2040_AS3394.kicad_sch]
2022-10-25 Added WIP photo of board
2022-10-28 Moved silkscreen designators so they're mostly readable. Rerouted some traces on bottom layer so they don't cross power planes with different potentials
    [RP2040_AS3394.kicad_pcb]
2022-11-05 First board prototype ordered from JLC with assembly
    [AS3394_PWM.kicad_sch, BOM-RP2040_AS3394.csv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]
2022-11-11 Fixed diff pair polarity
    [BOM-RP2040_AS3394.csv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]
2022-12-20 continuing work on second version
    [AS3394_PWM.kicad_sch, RP2040_AS3394.kicad_pcb, RP2040_AS3394.kicad_sch]
2023-02-07 added separate LDO for 3394, removed amp, designed psu board and made project for carrier board
    [AS3394_PWM.kicad_sch, Button_Matrix.kicad_sch, Button_Matrix_RP2040.kicad_pcb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]
2023-03-17 Updated to Kicad 7
    [AS3394_PWM.kicad_sch, RP2040_AS3394.kicad_pcb, RP2040_AS3394.kicad_sch]
2023-03-18 Reworked op-amp bias to use 5V LDO reference instead of 6.5V vin
    [AS3394_PWM.kicad_sch, RP2040_AS3394.kicad_pcb]
2023-09-14 Still WIP. Project mostly abandoned in favor of multiplexed DAC approach.
    [RP2040_AS3394.kicad_pcb]
